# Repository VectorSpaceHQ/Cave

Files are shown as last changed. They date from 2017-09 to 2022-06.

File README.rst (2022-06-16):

An open source, low-cost, Raspberry Pi powered, smart thermostat. Caves are generally cooler than nests.

Overview
=======
This program's goal is to maximize the amount of time spent in the comfort zone while minimizing the energy spent when the building is occupied.

Structure
========
This system is composed of a server, one or more thermostats, and optional nodes. Their purposes and interactions are as follows,

Server
-------
The server hosts the MySQL database and the web interface. Its purpose is to collect and analyze the sensor data from the thermostat(s) and any additional nodes, and use that information to direct the thermostat(s). In essence, the server is smart. The server can be a dedicated computer or it can run on the Raspberry Pi, alongside the thermostat program.

Thermostat
-------------
The thermostat measures temperature and directly interfaces with the wiring of the HVAC unit. It reports all measurements to the server and its actions are determined by the server. The thermostat is intended to be the Raspberry Pi.

Nodes
------
Nodes are optional pieces of hardware that provide additional sensor data to the MySQL database such as temperatures, humidity, and motion. Nodes might be of value in large spaces or in rooms isolated from the thermostat.

Nodes publish data using the MQTT protocol. This is done rather than modifying the MySQL database directly, simply because these nodes are small and rarely support SQL, as in the case of the ESP8266. The RPi subscribes to the MQTT channel and inserts the data it receives into the SQL database.

Installation
===========
clone the repository to the server and thermostat(s).
::
   git clone https://github.com/VectorSpaceHQ/Cave

Server
-------
Install mysql server on the server.
::
   sudo apt-get install mysql-server

Install supporting packages.
::
   sudo apt-get install python3-dev python3-pip python3-setuptools libmysqlclient-dev python3-mysql

Generate the initial MySQL database manually, then run ./src/database.py to create the tables
::
   mysql
   CREATE DATABASE hvac;
   quit
   ./src/database.py

You can confirm that the hvac database was added to your mysql server, by loging in at http://localhost/phpmyadmin/

Install required python packages.
::
   sudo pip3 install -r ./src/requirements.txt

Install Mosquitto on the server for MQTT brokering.
::
   sudo apt-get install mosquitto

Modify server/token.txt and server/server.conf files with appropriate values based on your wiring and preferences.

Thermostat
-----------
Install required python packages.
::
   sudo pip3 install -r ./thermostat/requirements.txt

Modify thermostat/token.txt and thermostat/thermostat.conf files with appropriate values based on your wiring and preferences.

Enable SPI and 1-Wire.
::
   sudo raspi-config
> Advanced Options > Enable SPI and 1-Wire

Services
copy cave_server.service to /etc/systemd/system/ on the server
copy cave_thermostat.service to /etc/systemd/system/ on the thermostat (RPi)

enable both of these services on their respective machines using
sudo systemctl enable cave_server.service
sudo systemctl enable cave_thermostat.service

Usage
=====
On the server,
::
   ./server/server.py start

On the RPi thermostat run,
::
   ./thermostat/thermostat.py start

MySQL database
=============
The database contains four tables.

ModuleInfo
-----------
This table contains an entry for each module (thermostat or node) connected to the system. It includes a unique ID, a description of the module's location, a firmware version, and boolean values to represent the presence of temperature, humidity, light, and motion sensors.

SensorData
-------------
This table logs all of the sensor readings, including the thermostat(s).

readingID, time, moduleID, location, temperature, humidity, light, sound, motion

ThermostatLog
-----------------
This table logs only the thermostat readings.

timeStamp, mode, moduleID, MinTemp, MaxTemp, actualTemp, coolOn, heatOn, fanOn, auxOn

ThermostatSet
----------------
This table provides the current directive for the thermostat(s). The server writes to this table and the thermostat reads from it.

timeStamp, moduleID, targetTemp, targetMode, expiryTime, entryNo

SystemLog
-----------
This table logs the state of the entire system.
timeStamp, Tthermostat, Toutside, Ttarget, Poccupancy

Testing
======
This software can be tested entirely on a single Raspberry Pi. Install the sample database found in /test, then run both the server.py and thermostat.py programs.
::
    mysql -uroot -p hvac < ./test/hvac_data.txt

    python3 -m unittest discover

Hardware
=======
Below is a wiring diagram for a Raspberry Pi zero with a temperature sensor, PIR sensor, and 4 channel relay.

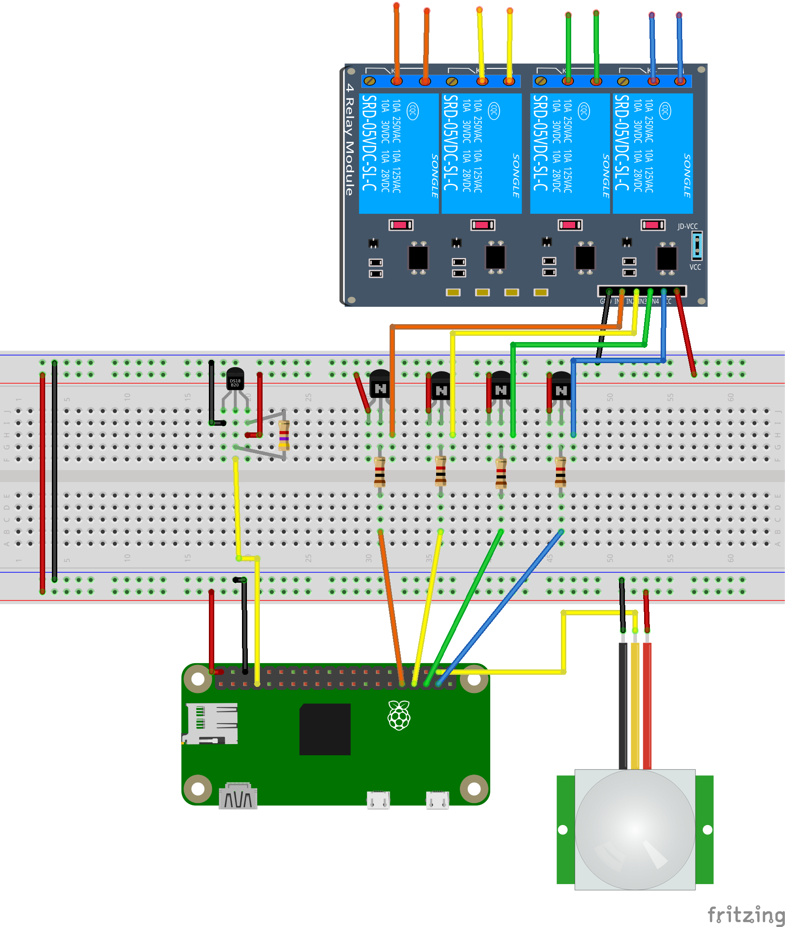
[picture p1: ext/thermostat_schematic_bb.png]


** Standard thermostat pins
*** Honeywell TH6320U2008
pin spacing of 5mm (https://www.mouser.com/ProductDetail/845-30.359), 1.3mm diameter. two 8 pin columns separated by 44.4mm (1.75in)
*** Honeywell TH5320U1001
pin spacing of 5mm (https://www.mouser.com/ProductDetail/845-30.359), 1.3mm diameter. One 9 pin column.

HVAC 101
=======
The following HVAC information is coppied directly from, https://github.com/Willseph/RaspberryPiThermostat

HVAC 101

HVAC (heating, ventilating, and air conditioning) can be implemented in different ways within a house or apartment, and varies for different countries based on the wiring and such. I'm not an expert in HVAC systems, I pretty much just learned enough to get by for this project, but here's a pretty useful guide: https://lrak.net/wiki/Thermostat_signals_and_wiring.html

My particular apartment uses a heat pump, which uses the very same compressor action for the air conditioner. The only difference is the air flow. This makes it possible to, in my case, use four wires from the HVAC panel behind the original thermostat for this project:

R (Red): This is the "common" wire, meaning that a circuit is completed when any of the other wires are connected to this one, hence the relay module.
G (Green): This is the signal for the fan, which becomes activated when connected to R.
Y (Yellow): This is the signal for the compressor. By default, the air flow is set to blow heat into the apartment.
O (Orange): This is the signal to reverse the air flow from the compressor. With Y and O both active, the flow changes to blow cool air into the apartment.
I broke this down to a pretty simple formula while I started writing the software for the controller:

R + G = Fan
R + G + Y = Heater
R + G + Y + O = Air conditioner

It's also very important to note that the wires coming out of my HVAC use a low voltage at 24V, not mains power. With a relay module completing the circuits, it should still work with mains electricity, but it is very dangerous and you should NOT mess with mains power unless you know exactly what you're doing! An accident involving high voltage and current can very easily kill you.

If your home HVAC does not use a compressor heat pump or for another reason you cannot use the same setup I'm using, you will have to do some research and potentially adjust the hvaccontroller.py script accordingly.

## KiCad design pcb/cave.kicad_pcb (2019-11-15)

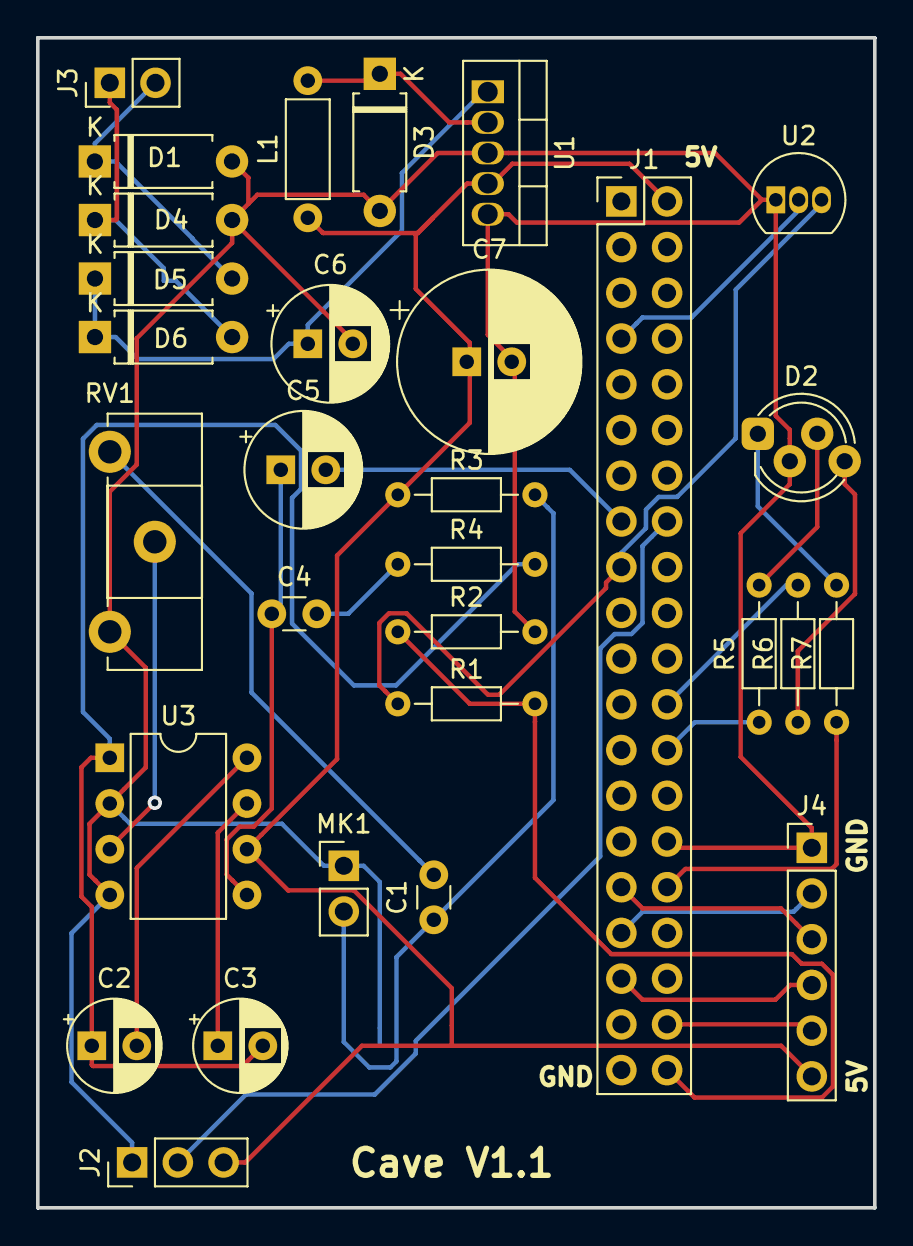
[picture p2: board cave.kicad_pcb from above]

Board: 2 copper layers, 46.5 x 65.0 mm, 30 parts (0 on the bottom side), 29 nets.

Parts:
C1: 0.1uF; C_Disc_D3.0mm_W1.6mm_P2.50mm
C2, C3: 10uF; CP_Radial_D5.0mm_P2.50mm
C4: 0.047uF; C_Disc_D3.0mm_W1.6mm_P2.50mm
C5, C6: 100uF; CP_Radial_D6.3mm_P2.50mm
C7: 1000uF; CP_Radial_D10.0mm_P2.50mm
D1, D4, D5, D6: D_Small; D_A-405_P7.62mm_Horizontal
D2: LED_RCBG; LED_D5.0mm-4_RGB_Staggered_Pins
D3: D_Schottky; D_A-405_P7.62mm_Horizontal
J1: Raspberry_Pi_2_3; PinHeader_2x20_P2.54mm_Vertical
J2: PIRsensor; PinHeader_1x03_P2.54mm_Vertical
J3: PWR; PinHeader_1x02_P2.54mm_Vertical
J4: RelayOutput; PinHeader_1x06_P2.54mm_Vertical
L1: 100uH; L_Axial_L5.3mm_D2.2mm_P7.62mm_Horizontal_Vishay_IM-1
MK1: Microphone; PinHeader_1x02_P2.54mm_Vertical
R1: R_PHOTO; R_Axial_DIN0204_L3.6mm_D1.6mm_P7.62mm_Horizontal
R2: 10K; R_Axial_DIN0204_L3.6mm_D1.6mm_P7.62mm_Horizontal
R3: 1K; R_Axial_DIN0204_L3.6mm_D1.6mm_P7.62mm_Horizontal
R4: 10; R_Axial_DIN0204_L3.6mm_D1.6mm_P7.62mm_Horizontal
R5, R6, R7: 220; R_Axial_DIN0204_L3.6mm_D1.6mm_P7.62mm_Horizontal
RV1: 10K; Potentiometer_ACP_CA14-H2,5_Horizontal
U1: LM2576S-5; TO-220-5_Vertical
U2: DS18B20; TO-92_Inline
U3: LM386; DIP-8_W7.62mm

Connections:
+3V3: J1.17, R1.1, U2.3
+5V: C7.1, J1.2, J2.3, J4.6, L1.1, R3.1, U1.4, U3.6
+24V: D1.1, D5.2, J3.2
-24V: D4.1, D6.2, J3.1
/MicInput: C5.2, J1.15
/PIR: J1.16, J2.2
GND: C6.2, C7.2, D1.2, D2.2, D3.2, D4.2, J1.30, J2.1, J4.1, MK1.1, R2.2, RV1.3, U1.3, U1.5, U2.1, U3.2, U3.4
unnamed: C1.1, MK1.2, R3.2
unnamed: C1.2, RV1.1
unnamed: C2.1, C3.2, R4.2, U3.1
unnamed: C2.2, U3.8
unnamed: C3.1, U3.7
unnamed: C4.1, C5.1, U3.5
unnamed: C4.2, R4.1
unnamed: C6.1, D5.1, D6.1, U1.1
unnamed: D2.1, R7.2
unnamed: D2.3, R5.2
unnamed: D2.4, R6.1
unnamed: D3.1, L1.2, U1.2
unnamed: J1.7, U2.2
unnamed: J1.24, R6.2
unnamed: J1.26, R5.1
unnamed: J1.31, J4.3
unnamed: J1.32, R7.1
unnamed: J1.33, J4.2
unnamed: J1.35, J4.4
unnamed: J1.38, J4.5
unnamed: J1.40, R1.2, R2.1
unnamed: RV1.2, U3.3

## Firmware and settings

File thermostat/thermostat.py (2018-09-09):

#!/usr/bin/env python3
# coding: utf-8
import sys
import subprocess
import os
import time
import RPi.GPIO as GPIO
import datetime
import configparser
import MySQLdb as mdb
import logging

# local imports. Can't figure out how this should actually be done
try:
    from thermostat.PythonDaemon import Daemon
except:
    from PythonDaemon import Daemon
try:
    from thermostat import RPiGetTemp
except:
    import RPiGetTemp
try:
    from thermostat import error
except:
    import error


#set working directory to where "thermDaemonDB.py" is
abspath = os.path.abspath(__file__)
dname = os.path.dirname(abspath)
# os.chdir(dname)

#read values from the config file
config = configparser.ConfigParser()
config.read(dname+"/thermostat.conf")

active_hysteresis = 1
inactive_hysteresis = 1.5
ORANGE_PIN = 6
YELLOW_PIN = 13
GREEN_PIN = 19
AUX_PIN = 26
PIR_PIN = 20
TEMP_PIN = 4
LIGHT_PIN = 21
AUX_ID = 1
# green_LED = 21

AUX_TIMER = 10 #minutes
AUX_THRESH = 0.2 #degrees


config = configparser.ConfigParser()
config.read(dname+"/token.txt")
CONN_PARAMS = (config.get('main','mysqlHost'), config.get('main','mysqlUser'),
        config.get('main','mysqlPass'), config.get('main','mysqlDatabase'),
        int(config.get('main','mysqlPort')))


class thermDaemon(Daemon):
    def init_module_info(self):
        """
        If the ModuleInfo table is empty, this function will populate it with default values.
        This table is required before any other tables can be populated.
        """
        self.motion = 0
        conn = mdb.connect(CONN_PARAMS[0],CONN_PARAMS[1],CONN_PARAMS[2],
                           CONN_PARAMS[3],port=CONN_PARAMS[4])
        cursor = conn.cursor()

        cursor.execute("SELECT * from ModuleInfo")
        targs = cursor.fetchall()
        if len(targs) == 0:
            cursor.execute("""INSERT ModuleInfo SET strDescription='thermostat', FirmwareVer='1', tempSense=1, humiditySense=0, lightSense=0, motionSense=1""")

        cursor.close()
        conn.commit()
        conn.close()

    def getMotion(self, PIR_PIN):
        print("MOVEMENT DETECTED")
        self.occupied = 1
        self.motion = 1
        self.last_movement = time.time()

        
    def checkLight(self):
        count = 0

        #Output on the pin for
        GPIO.setup(LIGHT_PIN, GPIO.OUT)
        GPIO.output(LIGHT_PIN, GPIO.LOW)
        time.sleep(0.1)
        
        #Change the pin back to input
        GPIO.setup(LIGHT_PIN, GPIO.IN)
    
        #Count until the pin goes high
        while (GPIO.input(LIGHT_PIN) == GPIO.LOW):
            count += 1
    
        if count < 100000:
            self.light = 1
            self.last_movement = time.time()

            
    def configureGPIO(self):
        GPIO.setmode(GPIO.BCM)
        GPIO.setup(ORANGE_PIN, GPIO.OUT)
        GPIO.setup(YELLOW_PIN, GPIO.OUT)
        GPIO.setup(GREEN_PIN, GPIO.OUT)
        GPIO.setup(AUX_PIN, GPIO.OUT)

        # GPIO.setup(red_LED, GPIO.OUT)
        # GPIO.setup(green_LED, GPIO.OUT)
        # GPIO.setup(blue_LED, GPIO.OUT)

        GPIO.setup(PIR_PIN, GPIO.IN)
        GPIO.setup(TEMP_PIN, GPIO.IN)
        GPIO.add_event_detect(PIR_PIN, GPIO.RISING, callback=self.getMotion)

        subprocess.Popen("echo " + str(ORANGE_PIN) + " > /sys/class/gpio/export", shell=True)
        subprocess.Popen("echo " + str(YELLOW_PIN) + " > /sys/class/gpio/export", shell=True)
        subprocess.Popen("echo " + str(GREEN_PIN) + " > /sys/class/gpio/export", shell=True)
        subprocess.Popen("echo " + str(AUX_PIN) + " > /sys/class/gpio/export", shell=True)

    def getHVACState(self):
        """
        orange: reverse airflow (cool)
        yellow: compressor
        green: fan
        aux:

        Return a 4 value tuple.
        (coolOn, heatOn, fanOn, auxOn)
        (0, 0, 0, 0) : idle
        elif hvacState == (1,0,1,0) or hvacState == (1,0,1,1) heating
        elif hvacState == (1,1,0,0): # it's cold out, why is the AC running?
        """
        orangeStatus = int(subprocess.Popen("cat /sys/class/gpio/gpio" + str(ORANGE_PIN) + "/value", shell=True, stdout=subprocess.PIPE).stdout.read().strip())
        yellowStatus = int(subprocess.Popen("cat /sys/class/gpio/gpio" + str(YELLOW_PIN) + "/value", shell=True, stdout=subprocess.PIPE).stdout.read().strip())
        greenStatus = int(subprocess.Popen("cat /sys/class/gpio/gpio" + str(GREEN_PIN) + "/value", shell=True, stdout=subprocess.PIPE).stdout.read().strip())
        auxStatus = int(subprocess.Popen("cat /sys/class/gpio/gpio" + str(AUX_PIN) + "/value", shell=True, stdout=subprocess.PIPE).stdout.read().strip())


        if orangeStatus == 1 and yellowStatus == 1 and greenStatus == 1 and auxStatus == 0:
          #cooling
            return (1, 1, 0, 0)

        elif yellowStatus == 1 and greenStatus == 1:
             #heating
            if auxStatus == 0:
                return (1, 0, 1, 0)
            else:
                return (1, 0, 1, 1)

        elif orangeStatus == 0 and yellowStatus == 0 and greenStatus == 0 and auxStatus == 0:
            #idle
            return (0, 0, 0, 0)

        elif orangeStatus == 0 and yellowStatus == 0 and greenStatus == 1 and auxStatus == 0:
            #fan
            return (1, 0 , 0, 0)

        else:
            #broken
            return (1, 1, 1, 1)

    def cool(self):
        print("COOLING")
        GPIO.output(ORANGE_PIN, True)
        GPIO.output(YELLOW_PIN, True)
        GPIO.output(GREEN_PIN, True)
        GPIO.output(AUX_PIN, False)
        return (1, 1, 0, 0)

    def heat(self):
        GPIO.output(ORANGE_PIN, False)
        GPIO.output(YELLOW_PIN, True)
        GPIO.output(GREEN_PIN, True)
        GPIO.output(AUX_PIN, False)
        return (1, 0, 1, 0)

    def aux(self):
        GPIO.output(ORANGE_PIN, False)
        GPIO.output(YELLOW_PIN, True)
        GPIO.output(GREEN_PIN, True)
        GPIO.output(AUX_PIN, True)
        return (1, 0, 1, 1)

    def fan(self):
        #to blow the rest of the heated / cooled air out of the system
        GPIO.output(ORANGE_PIN, False)
        GPIO.output(YELLOW_PIN, False)
        GPIO.output(GREEN_PIN, True)
        GPIO.output(AUX_PIN, False)
        return (1, 0, 0, 0)

    def idle(self):
        GPIO.output(ORANGE_PIN, False)
        GPIO.output(YELLOW_PIN, False)
        GPIO.output(GREEN_PIN, False)
        GPIO.output(AUX_PIN, False)
        #delay to preserve compressor
        print('Idling...')
        time.sleep(60)
        return (0, 0, 0, 0)

    def off(self):
        GPIO.output(ORANGE_PIN, False)
        GPIO.output(YELLOW_PIN, False)
        GPIO.output(GREEN_PIN, False)
        GPIO.output(AUX_PIN, False)
        return (0, 0, 0, 0)


    def getDBTargets(self):
        conDB = mdb.connect(CONN_PARAMS[0],CONN_PARAMS[1],CONN_PARAMS[2],CONN_PARAMS[3],port=CONN_PARAMS[4])
        cursor = conDB.cursor()

        cursor.execute("SELECT * from ThermostatSet")
        targs = cursor.fetchall()

        if len(targs) == 0:
            print("ERROR: database is empty. Execute server.py to initialize")
            sys.exit()

        cursor.close()
        conDB.close()
        return targs[0][:-1]


    def getTempList(self):
        """
        Return all temperatures from SensorData table.
        """
        conDB = mdb.connect(CONN_PARAMS[0],CONN_PARAMS[1],CONN_PARAMS[2],CONN_PARAMS[3],port=CONN_PARAMS[4])
        cursor = conDB.cursor()

        cursor.execute("SELECT MAX(moduleID) FROM ModuleInfo")
        totSensors = int(cursor.fetchall()[0][0])


        allModTemps=[]
        for modID in range(totSensors):
            try:
                queryStr = ("SELECT * FROM SensorData WHERE moduleID=%s ORDER BY readingID DESC LIMIT 1" % str(modID+1))
                cursor.execute(queryStr)
                allModTemps.append(float(cursor.fetchall()[0][4]))
            except:
                pass

        cursor.close()
        conDB.close()

        return allModTemps


    def logStatus(self, moduleID, targetTemp,actualTemp,hvacState):
        """
        Log status to the ThermostatLog table.
        """
        conDB = mdb.connect(CONN_PARAMS[0],CONN_PARAMS[1],CONN_PARAMS[2],CONN_PARAMS[3],port=CONN_PARAMS[4])
        cursor = conDB.cursor()


        cursor.execute("""INSERT ThermostatLog SET moduleID=%s, targetTemp=%s, actualTemp=%s,
                        coolOn=%s, heatOn=%s, fanOn=%s, auxOn=%s"""%
                        (str(moduleID),str(targetTemp),str(actualTemp),
                        str(hvacState[1]),str(hvacState[2]),str(hvacState[0]),str(hvacState[3])))

        cursor.close()
        conDB.commit()
        conDB.close()


    def server_mode(self):
        """
        The server is providing directive on what to do.
        """
        setTime, moduleID, targetTemp, target_mode, expiryTime = self.getDBTargets()
        if target_mode == 'heat':
            hvacState = self.heat()
        elif target_mode == 'cool':
            hvacState = self.cool()
        elif target_mode == 'idle':
            hvacState = self.idle()
        else:
            hvacState = self.idle()
        return hvacState


    def fallback_mode(self, auxBool=False):
        """
        If connection to the server is lost, assume space is occupied and try to
        maintain the comfort zone at all times.
        Set the HVAC unit to cool, heat, aux heat, or idle. Return the state of the HVAC unit.
        """
        hvacState=self.getHVACState()
        temp_f = RPiGetTemp.getTemp()

        T_min = 68
        T_max = 79

        if hvacState == (0,0,0,0): #idle
            if temp_f < (T_min - inactive_hysteresis):
                hvacState = self.heat()
            if temp_f > (T_max + inactive_hysteresis):
                hvacState = self.cool()

        else: # Active
            if auxBool:
                hvacState = self.aux()
            elif temp_f < (T_max - active_hysteresis):
                self.fan()
                time.sleep(30)
                hvacState = self.idle()
            # elif temp_f > (T_min + active_hysteresis):
            #     self.fan()
            #     time.sleep(30)
            #     hvacState = self.idle()

        print("setting HVAC state to: " + hvacState)

        return hvacState


    def report_sensor_data(self):
        """
        Get temperature, humidity, light, and motion sensor readings.
        Send them to the SensorData table in the server's database.
        """
        print("Reporting sensor data")
        temp_f = "NULL"
        humidity = "NULL"
        light = "NULL"

        temp_f = RPiGetTemp.getTemp()
        self.temp = temp_f

        conDB = mdb.connect(CONN_PARAMS[0],CONN_PARAMS[1],CONN_PARAMS[2],CONN_PARAMS[3],port=CONN_PARAMS[4])
        cursor = conDB.cursor()
        cursor.execute("INSERT SensorData SET moduleID=1, location='hallway', temperature=%s, motion=%s, light=%s"%(str(temp_f), int(self.motion), self.light))
        cursor.close()
        conDB.commit()
        conDB.close()


    def run(self,debug=False):
        """
        Every 60 seconds, send the thermostat temperature to the server's DB.
        Try to ask the server for directions. If the server cannot be reached, operate in a dumb
        mode that simply looks
        Every 5 seconds, set the HVAC state.
        """
        lastDB = time.time()
        lastAux = time.time()
        auxTemp = 0
        auxBool = False
        trueCount = 0
        movement_timeout = 60 # small only for debugging
        self.occupied = 0
        self.last_movement = time.time()
        self.init_module_info()
        self.configureGPIO()

        while True:
            try:
                # if GPIO.input(green_LED) == 1:
                #     GPIO.output(green_LED, 0)
                # else:
                #     GPIO.output(green_LED, 1)
                    
                abspath = os.path.abspath(__file__)
                dname = os.path.dirname(abspath)
                os.chdir(dname)

                now = time.time()
                dbElapsed = now - lastDB

                if self.getHVACState()[2] == 1:
                    auxElapsed = now - lastAux
                else:
                    auxElapsed = 0

                setTime, moduleID, targetTemp, targetMode, expiryTime = self.getDBTargets()

                moduleID = int(moduleID)
                targetTemp = int(targetTemp)

                tempList = self.getTempList()

                self.checkLight()

                if (time.time() - self.last_movement) > movement_timeout:
                    print("movement has stopped")
                    self.occupied = 0
                    self.motion = 0
                    self.light = 0

                if auxElapsed > AUX_TIMER*60:

                    curTemp = tempList[AUX_ID-1]
                    delta = float(curTemp)-float(auxTemp)
                    auxTemp = curTemp
                    lastAux = time.time()

                    if delta < AUX_THRESH and self.getHVACState()[2] == 1:
                        trueCount += 1
                        if auxBool is True or trueCount == 3:
                            auxBool = True
                            trueCount = 0
                        else:
                            auxBool = False
                    else:
                        auxBool = False

                print("dbElapsed = " +str(dbElapsed))
                if dbElapsed > 60:
                    self.report_sensor_data()
                    self.logStatus(moduleID, targetTemp, tempList[moduleID-1], self.getHVACState())
                    lastDB = time.time()

                # Try to get directive from server. Otherwise operate in fallback mode
                try:
                    print("server mode temporarily disabled")
                    self.server_mode()
                    # self.fallback_mode()
                except:
                    msg = "Operating in fallback mode"
                    print(msg)
                    error.notify_email(msg)
                    self.fallback_mode()


                print('Pin Value State:',self.getHVACState())
                print('Target Mode:',targetMode)
                print('Temp from DB:', tempList)
                print('Target Temp:', targetTemp)

                time.sleep(5)

            except Exception as e:
                if debug==True:
                    print(e)
                self.idle()
                exc_type, exc_obj, exc_tb = sys.exc_info()
                fname = os.path.split(exc_tb.tb_frame.f_code.co_filename)[1]

                logging.debug("error occurred at " + str(datetime.datetime.now()))
                logging.debug(fname)
                logging.debug(e)

                GPIO.cleanup()
                return


if __name__ == "__main__":
    daemon = thermDaemon(dname+'/thermDaemon.pid')

    if len(sys.argv) == 2:
        if 'start' == sys.argv[1]:
            
            daemon.run()
        elif 'stop' == sys.argv[1]:
            daemon.stop()
        elif 'restart' == sys.argv[1]:
            print("restarting")
            daemon.restart()
        elif 'debug' == sys.argv[1]:
            logging.basicConfig(filename=dname+'/thermostat.log',level=logging.DEBUG)
            try:
                daemon.run(True)
            except KeyboardInterrupt:
                GPIO.cleanup()
        else:
            print("Unknown command")
            sys.exit(2)
        sys.exit(0)
    else:
        print("usage: %s start|stop|restart" % sys.argv[0])
        sys.exit(2)

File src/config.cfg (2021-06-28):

[server]

# Weather setup. 
# WeatherModuleID should be the moduleID field that you have labeled
# as "outside".
WeatherModuleID = 0
OWM_APIKey = ec34436fb7333cce91604627b79782c0
Location = lynchburg, VA # city, state

# MySQL backups
mysqlBackup = True
mysqlBackupDir = /tmp


[thermostat]
# The comfort zone is based on ASHRAE recommendation in F. This value will modify that
# recommendation, increasing the comfort zone (widening the bounds) with positive
# values and decreasing with negative.
#1.5
comfort_offset = 0 


# This hasn't been implemented yet (Adam)
# Allowable offset from the programmed target
# This allows users to make a change to the programmed temperature within reason
allowed_user_temp_offset = 2   # user allowed +- this many degree modification
allowed_user_time = 2          # max hours a user can apply a change

# Let's say we want it to be 75, and it's in cooling mode.
# if the active_hysteresis is 0.5, it will cool to 74.5 before shutting off.
# on the other side, if the inactive_hysteresis is 1, the system will allow
# the indoor temp to reach 76 before turning cooling back on.
# adjust them to the particulars of your system / personal preference
active_hysteresis = 1
inactive_hysteresis = 1.5

ORANGE_PIN = 6
YELLOW_PIN = 13
GREEN_PIN = 19
AUX_PIN = 26

# Module ID that you wish to control the Aux heat.  This is to avoid
# Aux heat coming on for temperature fluctuations that may occur from
# a door opening, etc. This should probably be the sensor that is in
# the same place as your original thermostat.
AUX_ID = 1

PIR_PIN = 21
TEMP_PIN = 4

# RGB LED used for system status indication
# [Red, Green, Blue] pin numbers
RGB_LED = [17, 27, 22]


email = foo@bar.com

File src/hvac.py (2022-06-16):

#!/usr/bin/env python3
# coding: utf-8

import time
import RPi.GPIO as GPIO
from fysom import FysomGlobalMixin, FysomGlobal

GPIO.setmode(GPIO.BCM)

last_state_change = time.time()


def ready_for_change(e):
    """
    Prevent cycling of the compressor by applying a minimum
    time to wait between state changes.
    """
    SAFETY_TIMER = 500
    if (time.time() - last_state_change) > SAFETY_TIMER:
        print("Changing State")
        return True
    else:
        print("{} seconds until state change allowed".format(
            round(SAFETY_TIMER - (time.time() - last_state_change))))
        print("It has only been {:1.1f} seconds".format(time.time() - last_state_change))
        return False


    
class HVAC(FysomGlobalMixin):
    GSM = FysomGlobal(
        events=[('cool', 'idle', 'cool'),
                ('heat',  'idle', 'heat'),
                ('fan', 'idle', 'fan'),
                ('idle', ['idle', 'cool', 'heat'], 'idle')],
        callbacks={'on_before_idle': ready_for_change},
        initial='idle',
        state_field='state',
    )
        
    def __init__(self):
        # pin assignments
        self.REVERSE_PIN = 20  # reverse
        self.COMPRESSOR_PIN = 21 # compressor
        self.FAN_PIN = 19  # fan
        self.AUX_PIN = 18
        self.GREEN_LED = 7
        self.BLUE_LED = 8
        self.RED_LED = 12
        self.REVERSE_SENSE_PIN = 26
        self.COMPRESSOR_SENSE_PIN = 27
        self.FAN_SENSE_PIN = 25
        self.AUX_SENSE_PIN = 24

        GPIO.setup(self.REVERSE_PIN, GPIO.OUT)
        GPIO.setup(self.COMPRESSOR_PIN, GPIO.OUT)
        GPIO.setup(self.FAN_PIN, GPIO.OUT)
        GPIO.setup(self.AUX_PIN, GPIO.OUT)
        GPIO.setup(self.RED_LED, GPIO.OUT)
        GPIO.setup(self.GREEN_LED, GPIO.OUT)
        GPIO.setup(self.BLUE_LED, GPIO.OUT)

        GPIO.setup(self.REVERSE_SENSE_PIN, GPIO.IN)
        GPIO.setup(self.COMPRESSOR_SENSE_PIN, GPIO.IN)
        GPIO.setup(self.FAN_SENSE_PIN, GPIO.IN)
        GPIO.setup(self.AUX_SENSE_PIN, GPIO.IN)
        
        self.SAFETY_TIMER = 300 # minimum seconds between state changes, protects compressor
        self.last_state_change = 0

        self.state = 'idle'
        super(HVAC, self).__init__()
        self.onchangestate = self.printstatechange


    def printstatechange(self, e):
        print('change from {}, to {}'.format(e.src, e.dst))
        last_state_change = time.time()


    def turn_off(self):
        """
        Used to disable the system in event of errors.
        """
        GPIO.output(self.REVERSE_PIN, False)
        GPIO.output(self.COMPRESSOR_PIN, False)
        GPIO.output(self.FAN_PIN, False)
        GPIO.output(self.AUX_PIN, False)
        GPIO.output(self.BLUE_LED, False)
        GPIO.output(self.RED_LED, False)
        GPIO.output(self.GREEN_LED, False)
                
    def set_state(self, target_state):
        try:
            self.state = target_state
        except:
            print("FAILED to set state")

        if (time.time() - self.last_state_change) > self.SAFETY_TIMER:
            print("enough time has passed sinced last state change")
            self.last_state_change = time.time()

            print("setting state, current state = {}".format(self.current))
            
            if self.is_state("cool"):
                print("COOLING")
                GPIO.output(self.REVERSE_PIN, True)
                GPIO.output(self.COMPRESSOR_PIN, True)
                GPIO.output(self.FAN_PIN, True)
                GPIO.output(self.AUX_PIN, False)
                GPIO.output(self.BLUE_LED, True)
                GPIO.output(self.RED_LED, False)
                GPIO.output(self.GREEN_LED, False)                
            elif self.current == "heat":
                print("HEATING")
                GPIO.output(self.REVERSE_PIN, False)
                GPIO.output(self.COMPRESSOR_PIN, True)
                GPIO.output(self.FAN_PIN, True)
                GPIO.output(self.AUX_PIN, False)
                GPIO.output(self.BLUE_LED, False)
                GPIO.output(self.RED_LED, True)
                GPIO.output(self.GREEN_LED, False)                                
            elif self.current == "fan":
                print("FAN ON")
                GPIO.output(self.REVERSE_PIN, False)
                GPIO.output(self.COMPRESSOR_PIN, False)
                GPIO.output(self.FAN_PIN, True)
                GPIO.output(self.AUX_PIN, False)
                GPIO.output(self.BLUE_LED, True)
                GPIO.output(self.RED_LED, False)
                GPIO.output(self.GREEN_LED, True)                                
            elif self.current == "aux":
                GPIO.output(self.REVERSE_PIN, False)
                GPIO.output(self.COMPRESSOR_PIN, True)
                GPIO.output(self.FAN_PIN, True)
                GPIO.output(self.AUX_PIN, True)
                GPIO.output(self.BLUE_LED, True)
                GPIO.output(self.RED_LED, True)
                GPIO.output(self.GREEN_LED, True)                                
            elif self.current == "idle":
                print("IDLE")
                GPIO.output(self.REVERSE_PIN, False)
                GPIO.output(self.COMPRESSOR_PIN, False)
                GPIO.output(self.FAN_PIN, False)
                GPIO.output(self.AUX_PIN, False)
                GPIO.output(self.BLUE_LED, False)
                GPIO.output(self.RED_LED, False)
                GPIO.output(self.GREEN_LED, False)                                
            else:
                GPIO.output(self.REVERSE_PIN, False)
                GPIO.output(self.COMPRESSOR_PIN, False)
                GPIO.output(self.FAN_PIN, False)
                GPIO.output(self.AUX_PIN, False)
        else:
            remaining = self.SAFETY_TIMER - (time.time() - self.last_state_change)
            print("Safety timer has not expired: {}".format(remaining))


    def get_state(self):
        """
        Check the state of the output pins and determine their true position.
        """
        if GPIO.input(self.FAN_SENSE_PIN):
            print("Fan is on")
        if GPIO.input(self.COMPRESSOR_SENSE_PIN):
            print("Compressor is on")
        if GPIO.input(self.REVERSE_SENSE_PIN):
            print("Reverse flow is on")
        if GPIO.input(self.AUX_SENSE_PIN):
            print("AUX heat is on")

    
def test():
    hvac = HVAC()
    print(hvac.current)
    hvac.cool()
    print(hvac.current)
    time.sleep(1)
    if ready_for_change(''):
        hvac.idle()
    else:
        print("not ready")
    print(hvac.current)
    time.sleep(1)
    hvac.cool()
    print(hvac.current)


    
if __name__ == "__main__":
    test()

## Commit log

2017-08-14 corrected config file name
    [RPiGetTemp.py]
2017-08-15 Limit the sensor data query to last 50 entries
2017-08-15 fixed sorting of sensor data query
2017-08-26 removed fan actuation from idle mode. Needs to be smarter
2017-08-26 added weather back in. Fixed sort order of sensor data
    [server.py]
2017-08-27 idle was missing when outside temp is in comfort zone
    [server.py]
2017-08-28 began heat rate calculation
2017-08-30 beginning of an error handler for the thermostat
    [error.py]
2017-08-31 Added check_temp func to error.py. Removed Nooganeer's routes.py
    [error.py]
2017-09-05 initial commit of wiring schematic
    [thermostat_schematic.fzz]
2017-09-05 Remove TODO file. Switched to github's issues
2017-09-05 incorporating use of error checking
    [RPiGetTemp.py, error.py, thermostat.py]
2017-09-05 Changed sensordata entry from 'occupied' to 'motion'. Sensor shouldn't be smart enough to determine if space is occupied. It detects motion. Let the server determine whether the space is occupied bas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
2017-09-05 added analysis.py file
    [thermostat_schematic.fzz]
2017-09-22 fixed target_temp not being defined
    [server.py]
2018-08-13 added sample module to database-schema.sql to get people started
2018-08-17 added sytemd service and status LED to thermostat
2018-08-17 fixed idle pause time from debug time to actual time
    [server.py, thermostat.py]
2018-08-20 moving away from config file on thermostat. No need for user to modify pin numbers so readily
2018-08-21 fixed bug in creating SystemLog. Changed targetTemp to float in SQL
    [server.py]
2018-09-09 fixed local variable bugs in hvac
    [hvac.py]
2018-09-09 fixed bug in fallback_mode logic
    [error.py]
2018-09-09 minor fix to hvac get_state
    [hvac.py]
2018-09-16 fixed hvac set_state. pins weren't set as output
    [hvac.py]
2018-11-09 Major rework of server currently in server2.py
    [database.py, hvac.py]
2018-11-11 fixed bug in server.py getting temperature
    [server.py]
2018-11-12 added temperature forecasting
2018-11-15 added config.cfg
    [config.cfg]
2018-11-30 fixed errors in cave_thermostat.service and config parsing
    [thermostat.py]
2018-12-06 converted post_process.py to use peewee. Also got heat rate plot working
2019-02-05 Added simple radiative heat term
2019-03-21 Add pcb files
    [cave.kicad_pcb, cave.sch]
2019-04-16 Added basic tests for the PCB
2019-11-15 fixed rectifier layout and PIR position
    [cave.kicad_pcb, cave.sch]
2019-11-15 added more labels to pcb
    [cave.kicad_pcb]
2019-11-15 confirmed led_test.py works
2021-04-11 created custom footprint for 5mm pins and added to schematic
    [cave.sch]
2021-06-10 changes that I don't remember
    [config.cfg]
2021-06-28 fixed photoresistor test pin number
    [photoresistor_test.py]
2022-06-16 attempt to address bug where relays will remain in current position when software crashes. Should transition to idle state
    [hvac.py, led_test.py, photoresistor_test.py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]
